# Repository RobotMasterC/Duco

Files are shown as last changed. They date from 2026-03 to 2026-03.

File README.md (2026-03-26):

# Duco

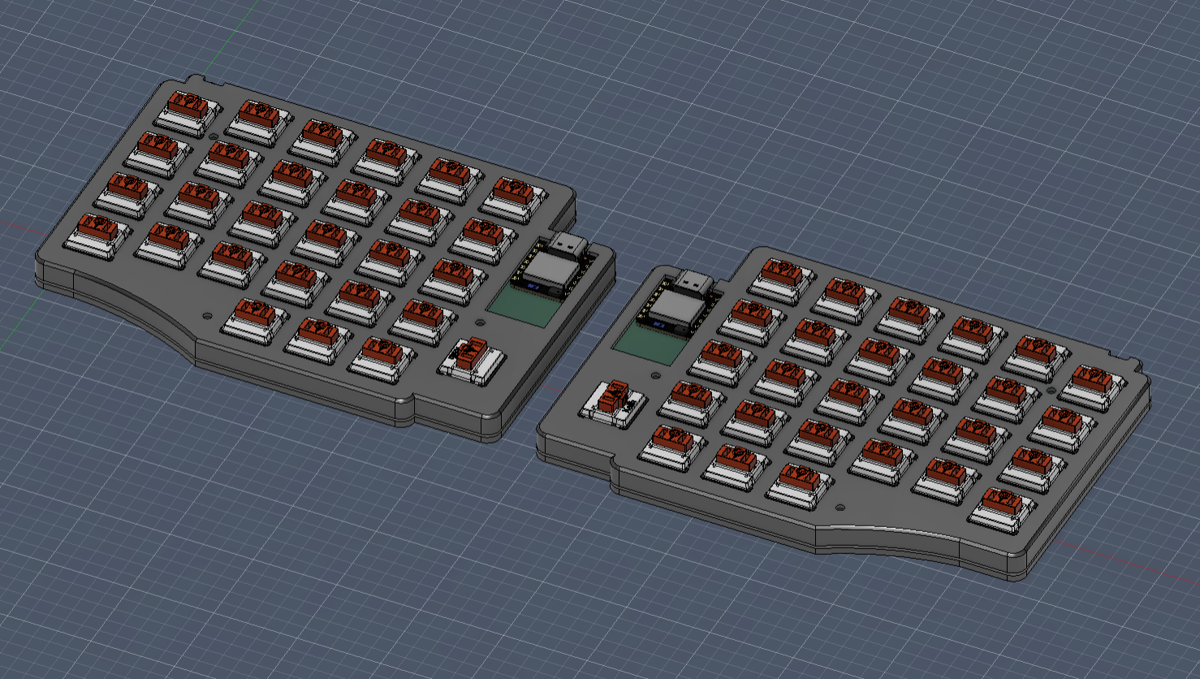
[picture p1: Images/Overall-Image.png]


Duco is a low profile split keyboard that has extra keys for macros and uses ZMK firmware

It was made for Hack Clubs [Blueprint](https://blueprint.hackclub.com) program!

## Images

### Schematic
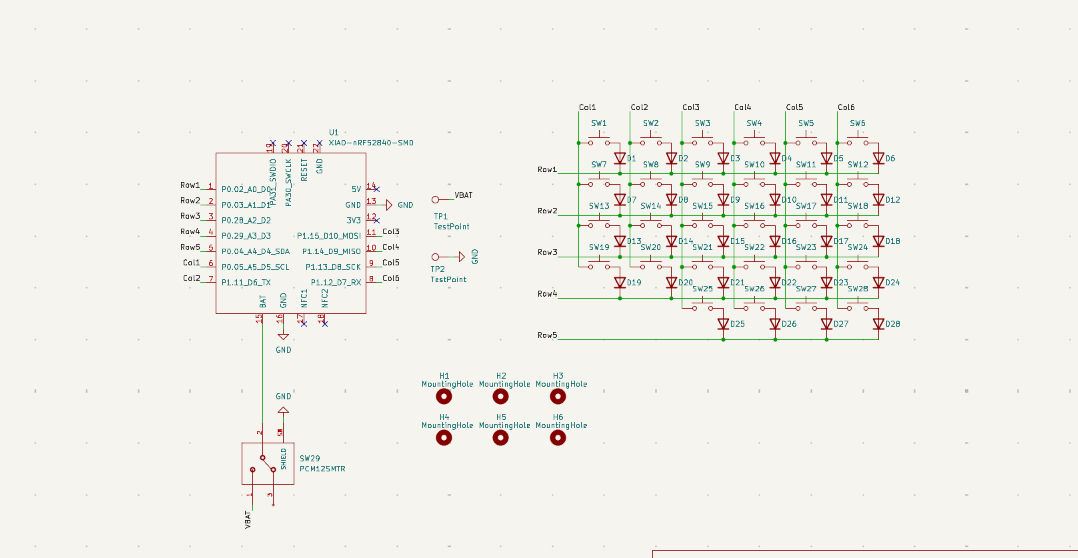
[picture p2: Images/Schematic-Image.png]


### PCB
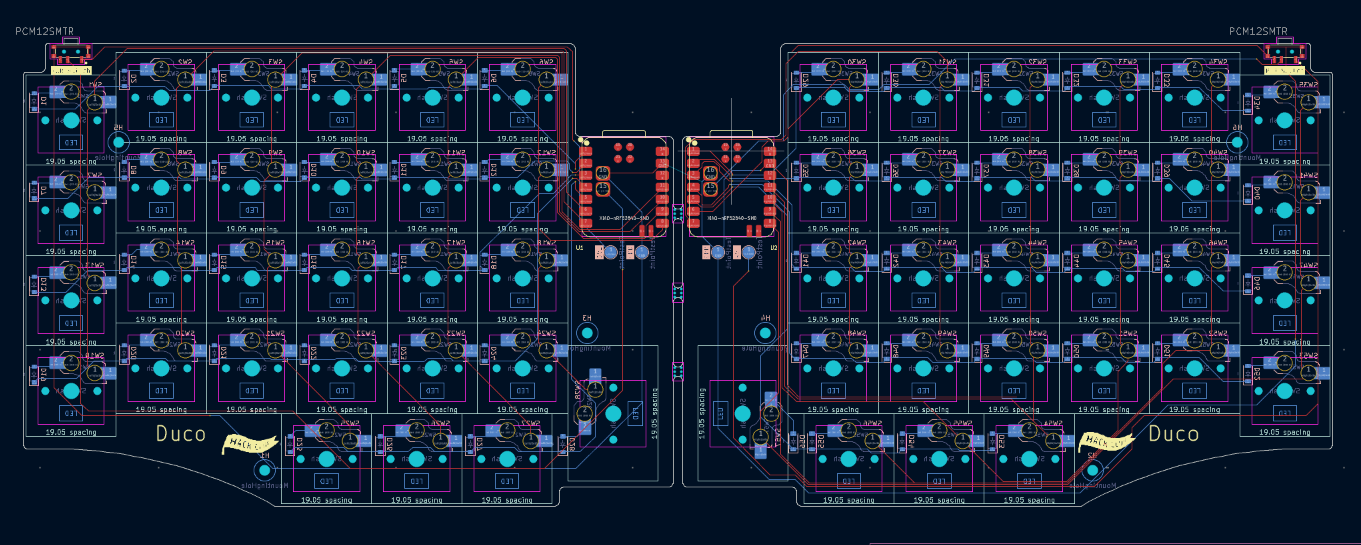
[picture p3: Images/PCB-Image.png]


### Top Case
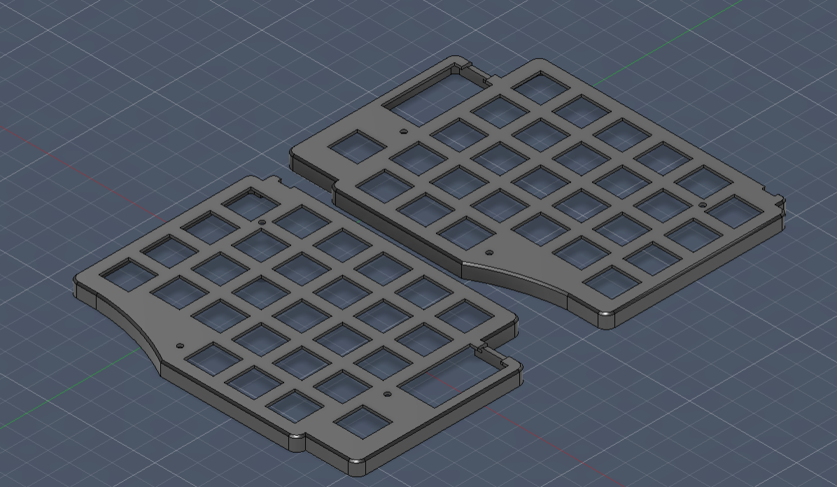
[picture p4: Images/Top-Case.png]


### Bottom Case
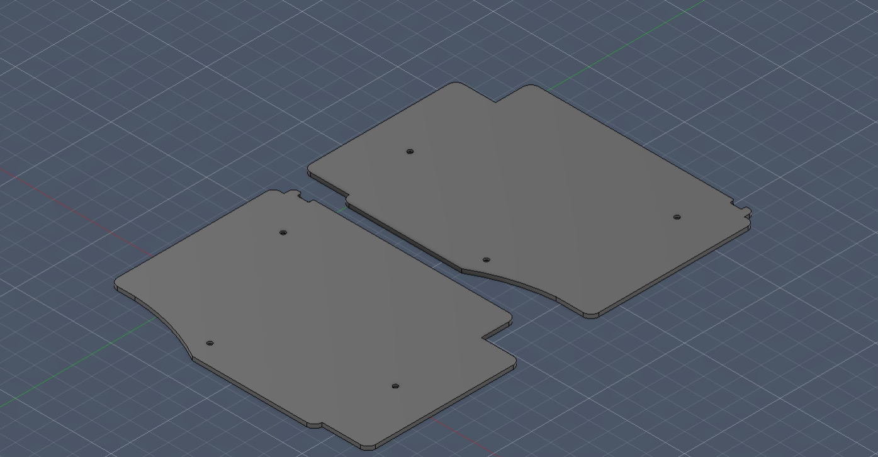
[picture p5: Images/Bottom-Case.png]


## Firmware

[Repository is here](https://github.com/RobotMasterC/zmk-config)

## BOM
Overall cost: $116.82
| Item  | Quantity | Unit Price | Total Price |
|---|---|---|---|
| [XIAO NRF52840](https://www.mouser.com/ProductDetail/Seeed-Studio/102010672?qs=sqEgtWRSLJ0SuHAgTfdO0A%3D%3D) | 2 | 10.4 | 20.8 |
| [Hotswap Socket (10 Pack)](https://www.mouser.com/ProductDetail/Adafruit/5118?qs=TCDPyi3sCW0NahZ3INJp%2FA%3D%3D) | 60 | 2.5 | 15 |
| [Red Choc Switches (10 Pack)](https://chosfox.com/products/kailh-chocs?variant=42514647613634) | 60 | 4.5 | 27 |
| [1N4148 Diodes](https://www.mouser.com/ProductDetail/Diotec-Semiconductor/1N4148W?qs=OlC7AqGiEDmsbkbAeXQtXg%3D%3D) | 56 | 0.045 | 2.7 |
| [PCM12SMTR Switch](https://www.mouser.com/ProductDetail/CK/PCM12SMTR?qs=mfFuHy8STfL3qrPSfCHA7w%3D%3D) | 2| 1.16 | 2.32 |
| [PCB](https://jlcpcb.com)| 5|| 14.8 |
| Case (3D Printed)| 4 | | 0 |
| Keycaps (3D Printed) | 56 || 0|
| Shipping (Mouser)||| 8.49|
| Shipping (JLCPCB)||| 11.99|
| Shipping (ChosFox)||| 6.8|
| Tarrif Estimate (Mouser)||| 6.27|
|||||
| Overall Cost||| 116.17|
| Grant Needed||| 89.38|
| (I will pay for the PCB to let this fit into tier 3) ||||

### Cart Screenshots

| JLCPCB | ChosFox | Mouser |
|---|---|---|
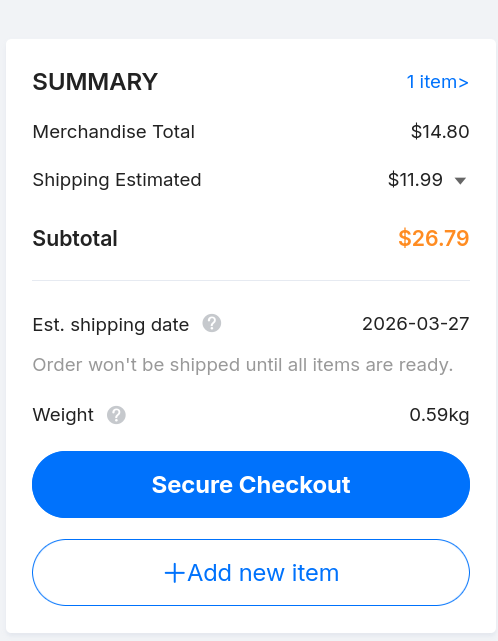
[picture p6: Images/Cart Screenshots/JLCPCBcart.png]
JLCPCBcart
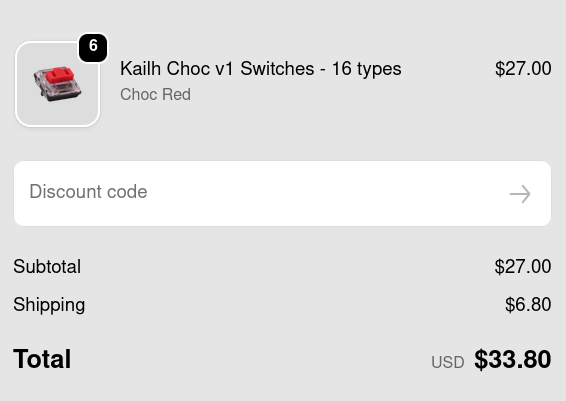
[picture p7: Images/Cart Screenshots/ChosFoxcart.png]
ChosFoxcart
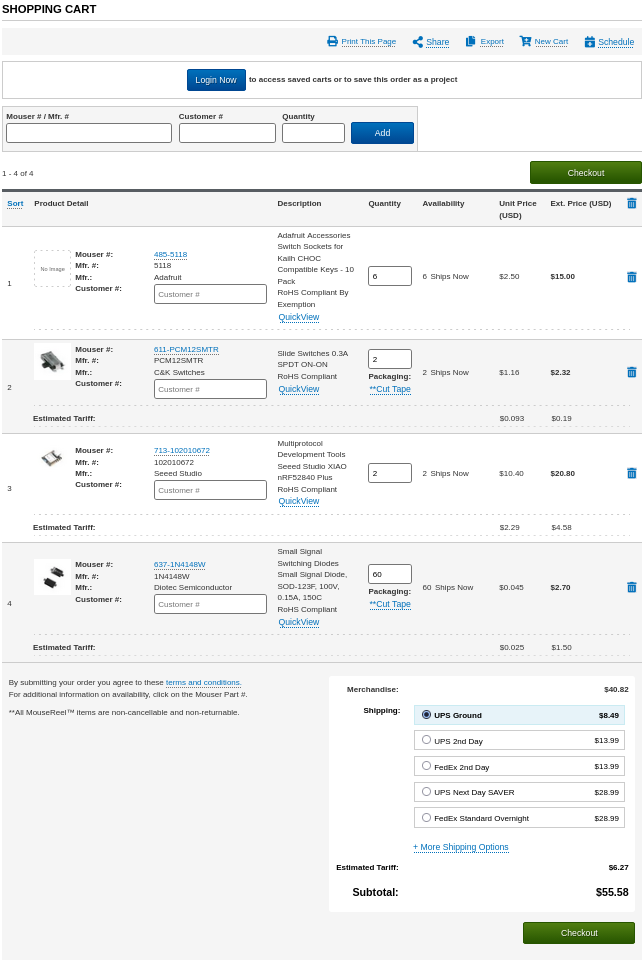
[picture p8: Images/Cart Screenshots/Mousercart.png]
Mousercart
| || |

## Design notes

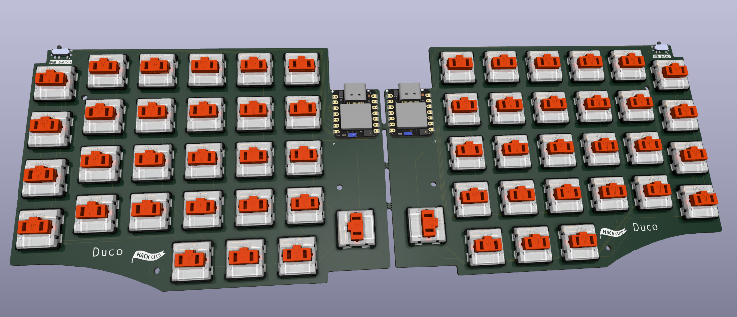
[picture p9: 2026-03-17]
Images/3D-PCB.png

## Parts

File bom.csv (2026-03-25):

Item | Quantity | Unit Price | Total Price | URL
XIAO NRF52840 | 2 | 10.4 | 20.8 | https://www.mouser.com/ProductDetail/Seeed-Studio/102010672?qs=sqEgtWRSLJ0SuHAgTfdO0A%3D%3D
Hotswap Socket (10 Pack) | 60 | 2.5 | 15 | https://www.mouser.com/ProductDetail/Adafruit/5118?qs=TCDPyi3sCW0NahZ3INJp%2FA%3D%3D
Red Choc Switches (10 Pack) | 60 | 4.5 | 27 | https://chosfox.com/products/kailh-chocs?variant=42514647613634
1N4148 Diodes | 56 | 0.045 | 2.7 | https://www.mouser.com/ProductDetail/Diotec-Semiconductor/1N4148W?qs=OlC7AqGiEDmsbkbAeXQtXg%3D%3D
PCM12SMTR Switch | 2 | 1.16 | 2.32 | https://www.mouser.com/ProductDetail/CK/PCM12SMTR?qs=mfFuHy8STfL3qrPSfCHA7w%3D%3D
PCB | 5 |  | 14.8 | https://jlcpcb.com
Case (3D Printed) | 4 |  | 0
Keycaps (3D Printed) | 56 |  | 0
Shipping (Mouser) |  |  | 8.49
Shipping (JLCPCB) |  |  | 11.99
Shipping (ChosFox) |  |  | 6.8
Tarrif Estimate (Mouser) |  |  | 6.27
Overall Cost |  |  | 116.17
Grant Needed |  |  | 89.38
(I will pay for the PCB to let this fit into tier 3)

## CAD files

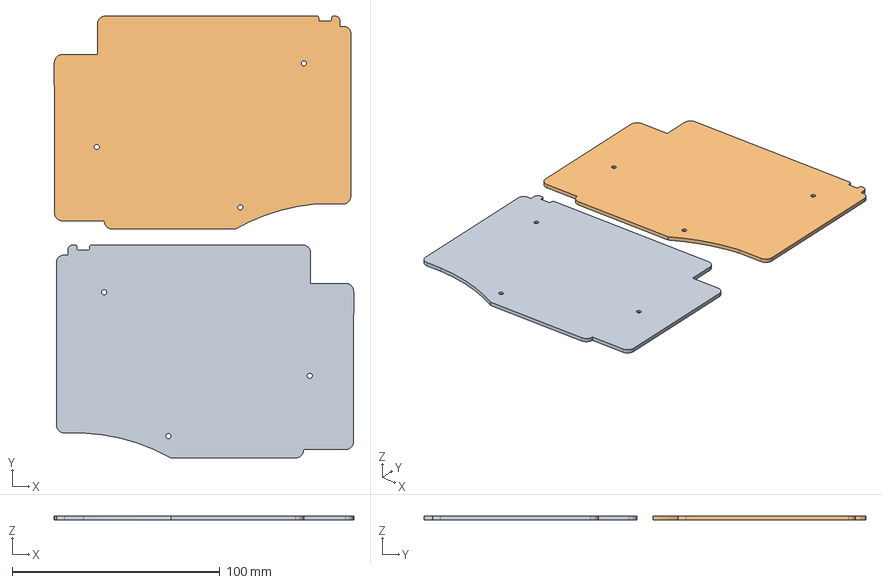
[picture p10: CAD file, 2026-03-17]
Case Files/Bottom Case.step
144.0 x 212.5 x 2.00 mm

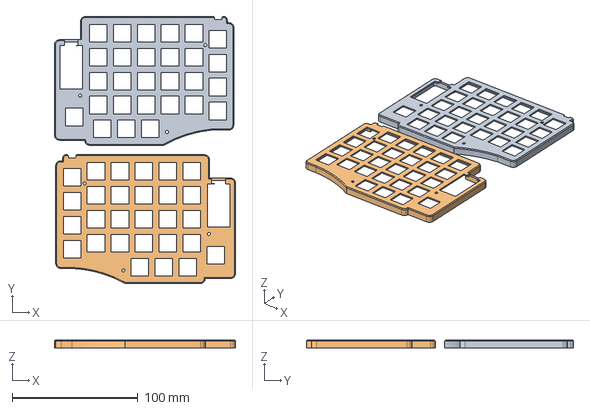
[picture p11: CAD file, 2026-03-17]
Case Files/Top Case.step
144.0 x 212.5 x 6.40 mm

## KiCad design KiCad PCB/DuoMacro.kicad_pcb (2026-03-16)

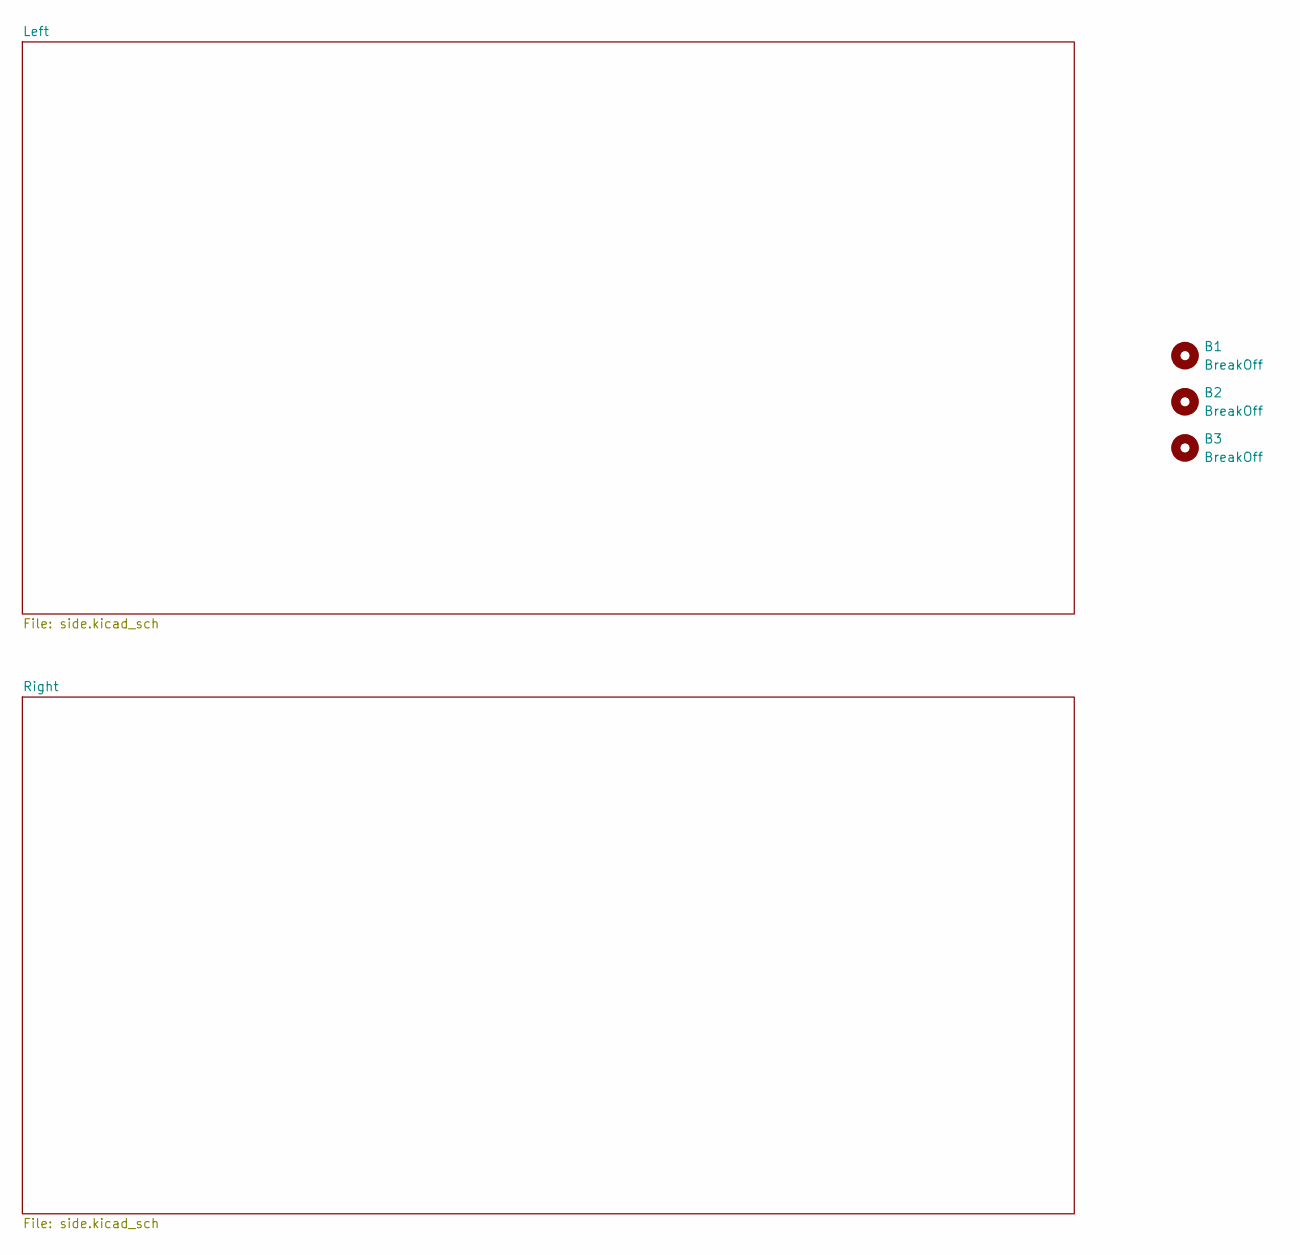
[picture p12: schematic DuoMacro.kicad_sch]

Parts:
B1, B2, B3: BreakOff; MouseBite-Slot_2.0x2.0mm_outset_D0.5mm_P0.85mm_3h

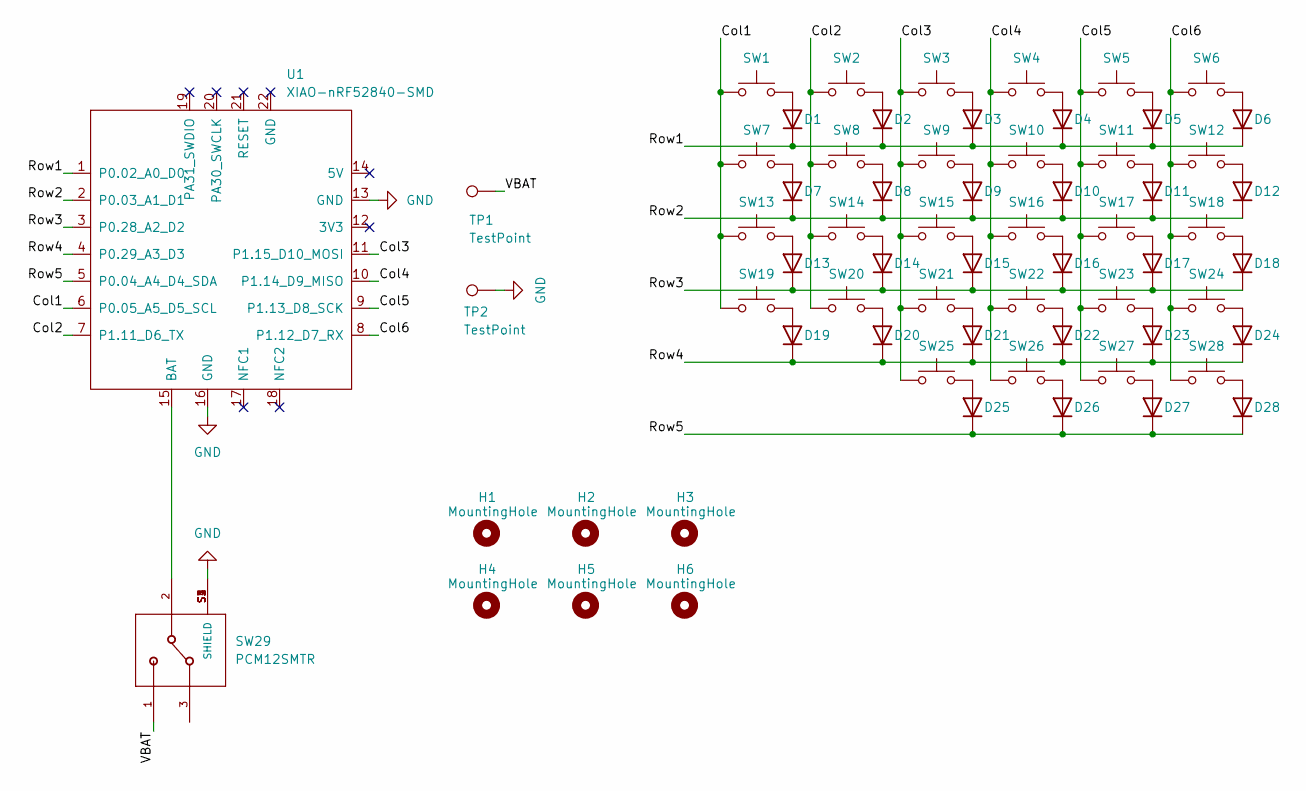
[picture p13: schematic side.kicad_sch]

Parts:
D1, D2, D3, D4, D5, D6, D7, D8, D9, D10, D11, D12, D13, D14, D15, D16, D17, D18, D19, D20, D21, D22, D23, D24, D25, D26, D27, D28: D_SOD-123
H1, H2, H3, H4, H5, H6: MountingHole; MountingHole_2.2mm_M2_Better
SW1, SW2, SW3, SW4, SW5, SW6, SW7, SW8, SW9, SW10, SW11, SW12, SW13, SW14, SW15, SW16, SW17, SW18, SW19, SW20, SW21, SW22, SW23, SW24, SW25, SW26, SW27: SW_Push; SW_choc_v1_HS_CPG135001S30_1u
SW28: SW_Push; SW_choc_v1_HS_CPG135001S30_1.5u
SW29: PCM12SMTR; SW_PCM12SMTR
TP1, TP2: TestPoint; TestPoint_Pad_D2.5mm
U1: XIAO-nRF52840-SMD; modified-XIAO-nRF52840-SMD

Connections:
/Left/Col1: SW1.1, SW7.1, SW13.1, SW19.1, U1.6 (P0.05_A5_D5_SCL)
/Left/Col2: SW2.1, SW8.1, SW14.1, SW20.1, U1.7 (P1.11_D6_TX)
/Left/Col3: SW3.1, SW9.1, SW15.1, SW21.1, SW25.1, U1.11 (P1.15_D10_MOSI)
/Left/Col4: SW4.1, SW10.1, SW16.1, SW22.1, SW26.1, U1.10 (P1.14_D9_MISO)
/Left/Col5: SW5.1, SW11.1, SW17.1, SW23.1, SW27.1, U1.9 (P1.13_D8_SCK)
/Left/Col6: SW6.1, SW12.1, SW18.1, SW24.1, SW28.1, U1.8 (P1.12_D7_RX)
/Left/Row1: D1.1 (K), D2.1 (K), D3.1 (K), D4.1 (K), D5.1 (K), D6.1 (K), U1.1 (P0.02_A0_D0)
/Left/Row2: D7.1 (K), D8.1 (K), D9.1 (K), D10.1 (K), D11.1 (K), D12.1 (K), U1.2 (P0.03_A1_D1)
/Left/Row3: D13.1 (K), D14.1 (K), D15.1 (K), D16.1 (K), D17.1 (K), D18.1 (K), U1.3 (P0.28_A2_D2)
/Left/Row4: D19.1 (K), D20.1 (K), D21.1 (K), D22.1 (K), D23.1 (K), D24.1 (K), U1.4 (P0.29_A3_D3)
/Left/Row5: D25.1 (K), D26.1 (K), D27.1 (K), D28.1 (K), U1.5 (P0.04_A4_D4_SDA)
/Left/VBAT: SW29.1, TP1.1
GND: SW29.S1 (SHIELD), SW29.S2 (SHIELD), SW29.S3 (SHIELD), SW29.S4 (SHIELD), TP2.1, U1.13 (GND), U1.16 (GND); also elsewhere on the board
unnamed: D1.2 (A), SW1.2
unnamed: D2.2 (A), SW2.2
unnamed: D3.2 (A), SW3.2
unnamed: D4.2 (A), SW4.2
unnamed: D5.2 (A), SW5.2
unnamed: D6.2 (A), SW6.2
unnamed: D7.2 (A), SW7.2
unnamed: D8.2 (A), SW8.2
unnamed: D9.2 (A), SW9.2
unnamed: D10.2 (A), SW10.2
unnamed: D11.2 (A), SW11.2
unnamed: D12.2 (A), SW12.2
unnamed: D13.2 (A), SW13.2
unnamed: D14.2 (A), SW14.2
unnamed: D15.2 (A), SW15.2
unnamed: D16.2 (A), SW16.2
unnamed: D17.2 (A), SW17.2
unnamed: D18.2 (A), SW18.2
unnamed: D19.2 (A), SW19.2
unnamed: D20.2 (A), SW20.2
unnamed: D21.2 (A), SW21.2
unnamed: D22.2 (A), SW22.2
unnamed: D23.2 (A), SW23.2
unnamed: D24.2 (A), SW24.2
unnamed: D25.2 (A), SW25.2
unnamed: D26.2 (A), SW26.2
unnamed: D27.2 (A), SW27.2
unnamed: D28.2 (A), SW28.2
unnamed: SW29.2, U1.15 (BAT)

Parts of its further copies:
D29, D30, D31, D32, D33, D34, D35, D36, D37, D38, D39, D40, D41, D42, D43, D44, D45, D46, D47, D48, D49, D50, D51, D52, D53, D54, D55, D56: D_SOD-123
SW30, SW31, SW32, SW33, SW34, SW35, SW36, SW37, SW38, SW39, SW40, SW41, SW42, SW43, SW44, SW45, SW46, SW47, SW48, SW49, SW50, SW51, SW52, SW53, SW54, SW55, SW56: SW_Push; SW_choc_v1_HS_CPG135001S30_1u
SW57: SW_Push; SW_choc_v1_HS_CPG135001S30_1.5u
SW58: PCM12SMTR; SW_PCM12SMTR
TP3, TP4: TestPoint; TestPoint_Pad_D2.5mm
U2: XIAO-nRF52840-SMD; modified-XIAO-nRF52840-SMD

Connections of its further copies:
/Right/Col1: SW30.1, SW36.1, SW42.1, SW48.1, U2.6 (P0.05_A5_D5_SCL)
/Right/Col2: SW31.1, SW37.1, SW43.1, SW49.1, U2.7 (P1.11_D6_TX)
/Right/Col3: SW32.1, SW38.1, SW44.1, SW50.1, SW54.1, U2.11 (P1.15_D10_MOSI)
/Right/Col4: SW33.1, SW39.1, SW45.1, SW51.1, SW55.1, U2.10 (P1.14_D9_MISO)
/Right/Col5: SW34.1, SW40.1, SW46.1, SW52.1, SW56.1, U2.9 (P1.13_D8_SCK)
/Right/Col6: SW35.1, SW41.1, SW47.1, SW53.1, SW57.1, U2.8 (P1.12_D7_RX)
/Right/Row1: D29.1 (K), D30.1 (K), D31.1 (K), D32.1 (K), D33.1 (K), D34.1 (K), U2.1 (P0.02_A0_D0)
/Right/Row2: D35.1 (K), D36.1 (K), D37.1 (K), D38.1 (K), D39.1 (K), D40.1 (K), U2.2 (P0.03_A1_D1)
/Right/Row3: D41.1 (K), D42.1 (K), D43.1 (K), D44.1 (K), D45.1 (K), D46.1 (K), U2.3 (P0.28_A2_D2)
/Right/Row4: D47.1 (K), D48.1 (K), D49.1 (K), D50.1 (K), D51.1 (K), D52.1 (K), U2.4 (P0.29_A3_D3)
/Right/Row5: D53.1 (K), D54.1 (K), D55.1 (K), D56.1 (K), U2.5 (P0.04_A4_D4_SDA)
/Right/VBAT: SW58.1, TP3.1
GND: SW58.S1 (SHIELD), SW58.S2 (SHIELD), SW58.S3 (SHIELD), SW58.S4 (SHIELD), TP4.1, U2.13 (GND), U2.16 (GND); also elsewhere on the board
unnamed: D29.2 (A), SW30.2
unnamed: D30.2 (A), SW31.2
unnamed: D31.2 (A), SW32.2
unnamed: D32.2 (A), SW33.2
unnamed: D33.2 (A), SW34.2
unnamed: D34.2 (A), SW35.2
unnamed: D35.2 (A), SW36.2
unnamed: D36.2 (A), SW37.2
unnamed: D37.2 (A), SW38.2
unnamed: D38.2 (A), SW39.2
unnamed: D39.2 (A), SW40.2
unnamed: D40.2 (A), SW41.2
unnamed: D41.2 (A), SW42.2
unnamed: D42.2 (A), SW43.2
unnamed: D43.2 (A), SW44.2
unnamed: D44.2 (A), SW45.2
unnamed: D45.2 (A), SW46.2
unnamed: D46.2 (A), SW47.2
unnamed: D47.2 (A), SW48.2
unnamed: D48.2 (A), SW49.2
unnamed: D49.2 (A), SW50.2
unnamed: D50.2 (A), SW51.2
unnamed: D51.2 (A), SW52.2
unnamed: D52.2 (A), SW53.2
unnamed: D53.2 (A), SW54.2
unnamed: D54.2 (A), SW55.2
unnamed: D55.2 (A), SW56.2
unnamed: D56.2 (A), SW57.2
unnamed: SW58.2, U2.15 (BAT)

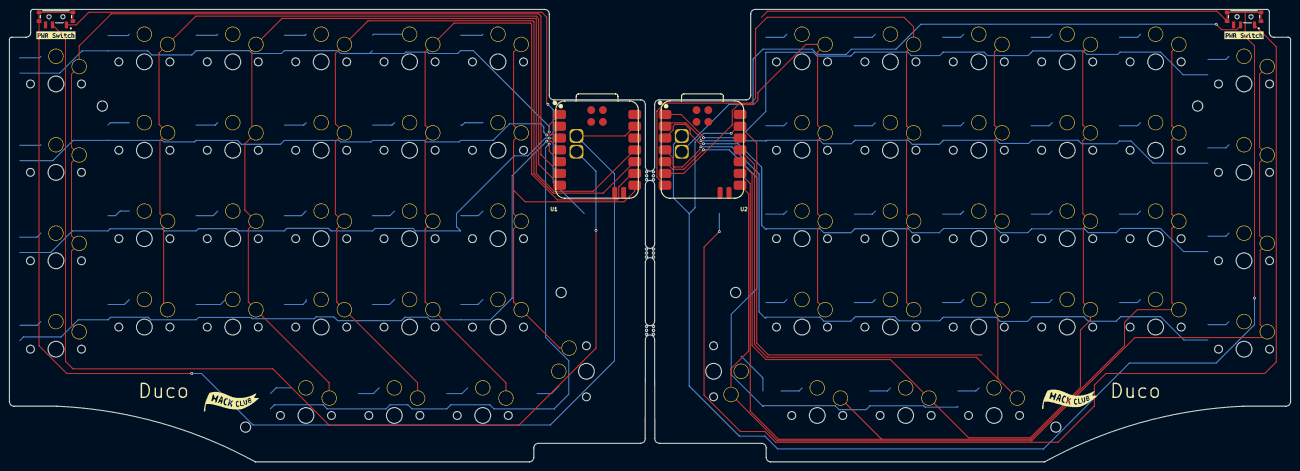
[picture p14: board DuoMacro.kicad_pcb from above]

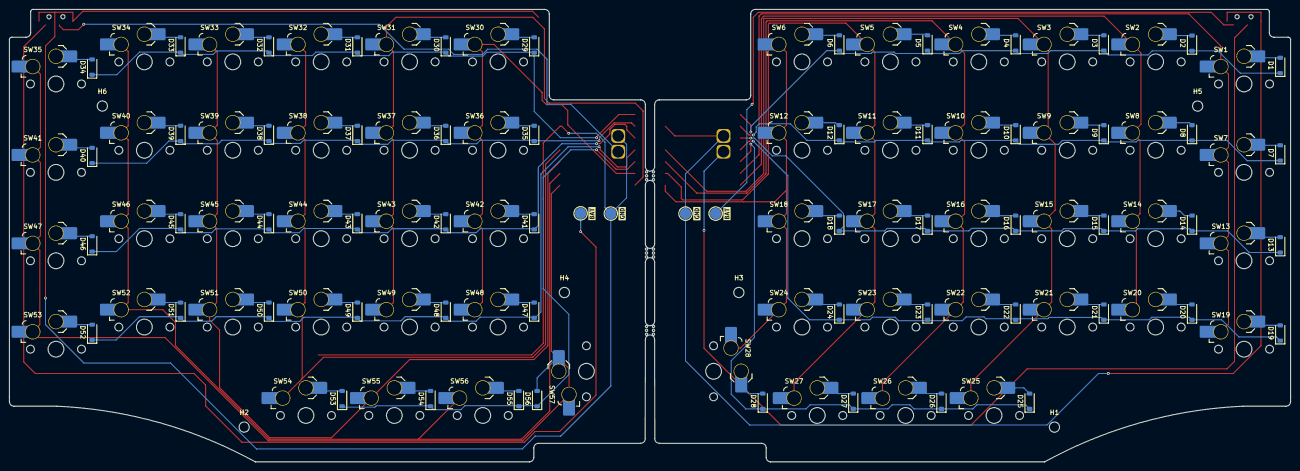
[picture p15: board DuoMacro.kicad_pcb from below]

Board: 2 copper layers, 276.1 x 97.5 mm, 135 parts (126 on the bottom side), 83 nets.

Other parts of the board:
kibuzzard-68F124C1, kibuzzard-68F124C1#2: G***; kibuzzard-68F124C1
kibuzzard-68F1247E, kibuzzard-68F1247E#2: G***; kibuzzard-68F1247E
kibuzzard-68F12504, kibuzzard-68F12504#2: G***; kibuzzard-68F12504

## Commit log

2026-03-16 Add all the files
    I know putting this all in one commit is a bad habit, this is all of the files for this project
    [DuoMacro.kicad_pcb, DuoMacro.kicad_sch, side.kicad_sch]
2026-03-17 Add images and files for the case
    [Bottom Case.step, Top Case.step]
2026-03-24 Final Updates
    [bom.csv]
2026-03-25 Update Readme
    Added cart screenshots to the readme
    [bom.csv]
2026-03-26 Add Case Image Files
2026-03-26 Add images for the Top and Bottom Case
